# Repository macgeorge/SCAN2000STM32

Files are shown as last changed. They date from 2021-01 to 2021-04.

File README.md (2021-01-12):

# SCAN2000-20 ScanCard for DMM6500 using an STM32 microcontrller
Please see the [project page](https://christidis.info/index.php/personal-projects/keithley-dmm-scanner-card-with-ssr) for more details

The repository includes
1. The schematics of the Scanner Card
2. The Bill of Materials
3. The Gerber files to build a Scanner Card
4. The STM32G070 code as well as the executable

The scanner card has been tested with a Keithley DMM6500 multimeter. It is also compatible with the Keithley 2000series multimeter. Jumper links can be used to change the identity of the scanner card (current configuration: 2000-20).

The solid state relays used are 160V capable (recommended 160V, absolute maximum 200V). Please do not measure voltages higher than that. Creepage between the HV circuit and the LV (control circuit) is adequate for 300V. 

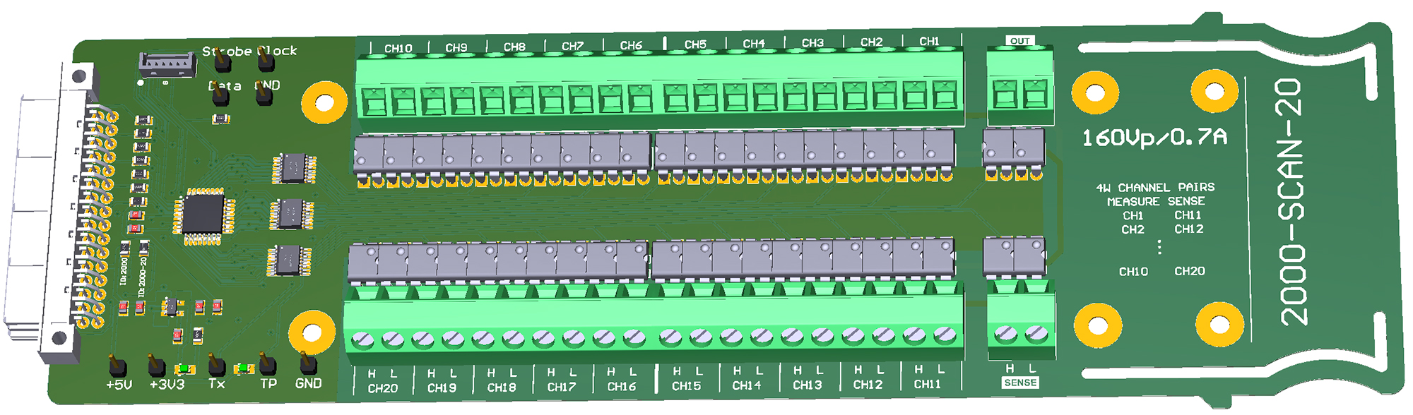
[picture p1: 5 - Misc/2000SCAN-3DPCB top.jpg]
ScanCardImage


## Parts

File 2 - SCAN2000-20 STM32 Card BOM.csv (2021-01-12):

Comment | Description | Designator | Footprint | LibRef | Quantity
TestPoint | Testpoint | +3V3, +5V, Clock, Data, GND, Strobe, TP, Tx | HDR1 | TestPoint | 9
Cap_1u_16V_0805 | Capacitor | C1, C2, C3, C4 | 0805 C | Cap_1u_16V_0805 | 4
Cap_100N_50V_0805 | Capacitor | C5, C6, C7 | 0805 C | Cap_100N_50V_0805 | 3
LED Green 0805 | Typical INFRARED GaAs LED | D1, D2 | 0805_G_LED | LED_Green_0805 | 2
SMT32G070 | STM32G070KBT6 LQFP32 | IC1 | LQFP-32_M | STM32G070KBT6 | 1
Molex 85050-0000 | Molex 85050-0000 | J1 | MOLEX 85050-0000 | Molex 85050-0000 | 1
6-pin 2.54mm header | Header, 6-Pin | P1 | Molex Picoblade 6way | Header 6 | 1
Conn_Phoenix_1869295 | Connector 10pin 5.08mm Phoenix 1869295 | P2, P3, P4, P5 | CONN X10 PHOENIX 1869295 | Conn_Phoenix_1869295 | 4
Conn_Phoenix_1869211 | Connector 2pin 5.08mm Phoenix 1869211 | P6, P7 | CONN X2 PHOENIX 1869211 | Conn_Phoenix_1869211 | 2
Res_330R_0805 | Resistor | R1, R2, R3, R4, R11 | 0805 R | Res_330R_0805 | 5
Res_0Ohm_0805 | Resistor | R5, R10 | 0805 R | Res_0Ohm_0805 | 2
Res_10K0_0805 | Resistor | R6, R7, R8, R9 | 0805 R | Res_10K0_0805 | 4
Res_330R_Pack8 | Isolated Resistor Network | R12, R13, R14, R15, R16, R17 | QSOP-QR16_M | Res_330R_Pack8 | 6
Res_2m_2512 | Resistor | R18, R19, R20, R21, R22, R23, R24, R25 | 2512 R | Res_2m0_2512 | 8
3.3V LDO | Single Output Fast Transient Response LDO, 200 mA, Fixed 3.3 V Output, 1.7 to 5.5 V Input, with Reverse Current Protection, 5-pin SOT-23 (DBV), -40 to 85 degC, Green (RoHS & no Sb/Br) | U1 | SOT-23-CT5_M | TPS73233DBVR | 1
TLP3558A | 4-Pin Phototransistor Optocoupler | U2, U3, U4, U5, U6, U7, U8, U9, U10, U11, U12, U13, U14, U15, U16, U17, U18, U19, U20, U21, U22, U23, U24, U25, U26, U27, U28, U29, U30, U31, U32, U33, U34, U35, U36, U37, U38, U39, U40, U41, U42, U43, U44, U45 | DIP4 - HV | TLP3558A | 44

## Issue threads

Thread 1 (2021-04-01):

Missing main.h file

cjkraz, 2021-04-01:
Can't compile due to missing "main.h" header in "SCAN2000.c".

fssup, 2021-05-03:
Haven't tried compiling yet, but it looks to my eye that everything is included in the c file, hence not needing a head (.h) file. Probably you need to fix your makefile? Can you post your makefile you're trying to get working?

cjkraz, 2021-11-26:
I'm using the Arduino IDE to compile this source right now. (I typically develop on TI Devices).

The updates are a major improvement. The issue I'm currently facing is around the USART4 definition:

```
C:\Users\Work\OneDrive\Documents\Arduino\sketch_nov26a\sketch_nov26a.ino: In function 'int fputc(int, FILE*)':
sketch_nov26a:199:34: error: 'USART4' was not declared in this scope; did you mean 'USART1'?
  199 |   while(LL_USART_IsActiveFlag_TC(USART4) != 1);
      |                                  ^~~~~~
      |                                  USART1
sketch_nov26a:200:27: error: 'USART4' was not declared in this scope; did you mean 'USART1'?
  200 |   LL_USART_TransmitData8 (USART4, charac);
      |                           ^~~~~~
      |                           USART1
C:\Users\Work\OneDrive\Documents\Arduino\sketch_nov26a\sketch_nov26a.ino: In function 'void USART4_Init()':
sketch_nov26a:251:28: error: 'LL_APB1_GRP1_PERIPH_USART4' was not declared in this scope; did you mean 'LL_APB1_GRP1_PERIPH_USART2'?
  251 |   LL_APB1_GRP1_EnableClock(LL_APB1_GRP1_PERIPH_USART4);
      |                            ^~~~~~~~~~~~~~~~~~~~~~~~~~
      |                            LL_APB1_GRP1_PERIPH_USART2
sketch_nov26a:273:17: error: 'USART4' was not declared in this scope; did you mean 'USART1'?
  273 |   LL_USART_Init(USART4, &USART_InitStruct);
      |                 ^~~~~~
      |                 USART1
sketch_nov26a:286:34: error: 'LL_DMAMUX_REQ_USART4_TX' was not declared in this scope; did you mean 'LL_DMAMUX_REQ_USART2_TX'?
  286 |   DMA_InitStruct.PeriphRequest = LL_DMAMUX_REQ_USART4_TX;
      |                                  ^~~~~~~~~~~~~~~~~~~~~~~
      |                                  LL_DMAMUX_REQ_USART2_TX
C:\Users\Work\OneDrive\Documents\Arduino\sketch_nov26a\sketch_nov26a.ino: In function 'void UARTSendDMA()':
sketch_nov26a:299:34: error: 'USART4' was not declared in this scope; did you mean 'USART1'?
  299 |   while(LL_USART_IsActiveFlag_TC(USART4) != 1); // wait for previous transfer to finish
      |                                  ^~~~~~
      |                                  USART1
In file included from C:\Users\Work\AppData\Local\Arduino15\packages\STMicroelectronics\hardware\stm32\2.1.0\cores\arduino/stm32/clock.h:19,
                 from C:\Users\Work\AppData\Local\Arduino15\packages\STMicroelectronics\hardware\stm32\2.1.0\cores\arduino/wiring_time.h:23,
                 from C:\Users\Work\AppData\Local\Arduino15\packages\STMicroelectronics\hardware\stm32\2.1.0\cores\arduino/wiring.h:38,
                 from C:\Users\Work\AppData\Local\Arduino15\packages\STMicroelectronics\hardware\stm32\2.1.0\cores\arduino/Arduino.h:36,
                 from sketch\sketch_nov26a.ino.cpp:1:
C:\Users\Work\OneDrive\Documents\Arduino\sketch_nov26a\sketch_nov26a.ino: At global scope:
C:\Users\Work\AppData\Local\Arduino15\packages\STMicroelectronics\hardware\stm32\2.1.0\cores\arduino/stm32/stm32_def.h:109:25: error: variable or field '_Error_Handler' declared void
  109 | #define Error_Handler() _Error_Handler(__FILE__, __LINE__)
      |                         ^~~~~~~~~~~~~~
C:\Users\Work\OneDrive\Documents\Arduino\sketch_nov26a\sketch_nov26a.ino:558:6: note: in expansion of macro 'Error_Handler'
  558 | void Error_Handler()
      |      ^~~~~~~~~~~~~
exit status 1
'USART4' was not declared in this scope; did you mean 'USART1'?

```

cjkraz, 2021-12-13:
This should be closed. I had the wrong board selected. Your updates did resolve a number of issues I originally had with the code base.

Really appreciate the update!

Closed 2021-12-13.

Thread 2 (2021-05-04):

Include full sources and schematics

ddavidebor, 2021-05-04:
Hi,

I would like to use this as a source project to create the thermocouple card.
Could you add to the repo:
- full altium proj (PcbDoc, SchDoc, PrjPcb, etc)
- Full STM32 project including makefile and IDE data

cjkraz, 2021-11-26:
I believe this may be made in KiCad. I am interested in the design files if willing to share. I was looking at implementing a pure analog solution with shift registers to work around the issues of programming an MCU to handle the bit stream from the DMM6500; adjusting this project would be an easy starting point.

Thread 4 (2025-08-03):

Gerber Drillfiles

ep092, 2025-08-03:
SCAN2000-20 PCB.TXT has an offset to gerber layers
Holesize in SCAN2000-20 PCB-5_PTH_Drill.gbr is partially different then in SCAN2000-20 PCB.TXT

Could you please share the Altium files?

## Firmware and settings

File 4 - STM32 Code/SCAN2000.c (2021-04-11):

#include <stdio.h>
#include <string.h>
#include "stm32g0xx_ll_rcc.h"
#include "stm32g0xx_ll_bus.h"
#include "stm32g0xx_ll_system.h"
#include "stm32g0xx_ll_exti.h"
#include "stm32g0xx_ll_cortex.h"
#include "stm32g0xx_ll_utils.h"
#include "stm32g0xx_ll_pwr.h"
#include "stm32g0xx_ll_dma.h"
#include "stm32g0xx_ll_usart.h"
#include "stm32g0xx_ll_gpio.h"

#define MAXALLOWEDONCHANNELS 6

#define CH21STATEOFF		0
#define CH21STATEOUT		1
#define CH21STATESENSE	2
#define CH21REQOFF			0
#define CH21REQOUT			1
#define CH21REQSENSE		2
#define CH21NOREQ				3

void SystemClock_Config(void);
void GPIO_Init(void);
void USART4_Init(void);
void UARTSendDMA(void);

uint64_t receivedSequence = 0;
uint8_t receivedCounter = 0;
int8_t numberOfChannelsActive = 0;
uint32_t channelState = 0;
uint8_t channel21State = CH21STATEOFF;
uint8_t channel21Req = CH21NOREQ;
uint8_t channel21DMMCommand = CH21REQOFF;
uint8_t channelSequence[] = {11, 12, 13, 14, 15, 16, 17, 18, 19, 20, 1, 2, 3, 4, 5, 6, 7 , 8, 9, 10, 21};
GPIO_TypeDef* GPIOsequence[] = {GPIOA, GPIOA, GPIOA, GPIOA, GPIOB, GPIOB, GPIOB, GPIOB, GPIOB, GPIOB, GPIOA, GPIOB, GPIOB, GPIOB, GPIOA, GPIOA, GPIOA, GPIOA, GPIOA, GPIOA};
uint32_t PinSequence[] = {LL_GPIO_PIN_10, LL_GPIO_PIN_11, LL_GPIO_PIN_12, LL_GPIO_PIN_15, LL_GPIO_PIN_3, LL_GPIO_PIN_4, LL_GPIO_PIN_5, LL_GPIO_PIN_6, LL_GPIO_PIN_7, LL_GPIO_PIN_8, LL_GPIO_PIN_8, LL_GPIO_PIN_2, LL_GPIO_PIN_1, LL_GPIO_PIN_0, LL_GPIO_PIN_7, LL_GPIO_PIN_6, LL_GPIO_PIN_5, LL_GPIO_PIN_4, LL_GPIO_PIN_3, LL_GPIO_PIN_2};
uint8_t uartsinglemessage[40], uartbuffer[2000], uarttransmitbuffer[2000];	
int main(void)
{
  LL_APB2_GRP1_EnableClock(LL_APB2_GRP1_PERIPH_SYSCFG);
  LL_APB1_GRP1_EnableClock(LL_APB1_GRP1_PERIPH_PWR);

  SystemClock_Config();

  GPIO_Init();
	LL_GPIO_ResetOutputPin(GPIOA, LL_GPIO_PIN_1); /* turn on led */
  USART4_Init();
	printf("\n===============\nBoot\n");
	LL_GPIO_SetOutputPin(GPIOA, LL_GPIO_PIN_1); /* turn off led */
  
	while (1)
  {

	}
}

void EXTI4_15_IRQHandler(void)
{
  if (LL_EXTI_IsActiveRisingFlag_0_31(LL_EXTI_LINE_14) != RESET)
  {	/* Clock interrupt */
    LL_EXTI_ClearRisingFlag_0_31(LL_EXTI_LINE_14);
		receivedSequence = receivedSequence << 1;
		receivedSequence |= LL_GPIO_IsInputPinSet(GPIOB, LL_GPIO_PIN_9);
		receivedCounter++;
  }
  if (LL_EXTI_IsActiveRisingFlag_0_31(LL_EXTI_LINE_15) != RESET)
  {
		/* Strobe Interrupt */
    LL_EXTI_ClearRisingFlag_0_31(LL_EXTI_LINE_15);
		LL_GPIO_TogglePin(GPIOA, LL_GPIO_PIN_1); /* toggle led */
		uartbuffer[0] = '\0';
		
		if (receivedCounter != 48)	{
			sprintf((char *)uartsinglemessage, "Warning: 48 clocks not received, %d\n", receivedCounter);
			strcat((char *)uartbuffer, (char *)uartsinglemessage);
		}
		
		if (receivedSequence != 0x0) {
			/* if no command, do nothing */
			uint8_t counter;
			for (counter = 0 ; counter<20 ; counter++) {
				if ((receivedSequence & ((uint64_t)1<<(2*counter))) !=0) {
					/* turn off channel */
					LL_GPIO_ResetOutputPin(GPIOsequence[channelSequence[counter]-1], PinSequence[channelSequence[counter]-1]);
					numberOfChannelsActive--;
					channelState &= ~((long)1<<(channelSequence[counter]-1));
					sprintf((char *)uartsinglemessage, "CH%d OFF\n", channelSequence[counter]);
					strcat((char *)uartbuffer, (char *)uartsinglemessage);
					if (numberOfChannelsActive<0) 
					{
						sprintf((char *)uartsinglemessage, "Warning too many ssr off requests\n");
						strcat((char *)uartbuffer, (char *)uartsinglemessage);
						numberOfChannelsActive = 0;
					}
				}
				
				if ((receivedSequence & ((uint64_t)1<<(2*counter+1))) !=0) {
					/* turn on channel */
					if (numberOfChannelsActive < MAXALLOWEDONCHANNELS) {
						LL_GPIO_SetOutputPin(GPIOsequence[channelSequence[counter]-1], PinSequence[channelSequence[counter]-1]);
						numberOfChannelsActive++;
						channelState |= (1<<(channelSequence[counter]-1));
						sprintf((char *)uartsinglemessage, "CH%d ON\n", channelSequence[counter]);
						strcat((char *)uartbuffer, (char *)uartsinglemessage);
					}
					else
					{
						sprintf((char *)uartsinglemessage, "Error, maximum allowed of on ssrs reached. CH%d did not switch on\n", channelSequence[counter]);
						strcat((char *)uartbuffer, (char *)uartsinglemessage);;
					}
				}
			}
			
			/* channel 21 */
			if ((channelState & 0xFFC00)==0) {
				/* If channels 11 to 20 not used, turn off both bus2 switches */
					channel21Req = CH21REQOFF;
			}
			else {
				/* But turn the bus on again, on the next command for CH11 to CH20 use */
				channel21Req = channel21DMMCommand;
			}
			if ((receivedSequence & ((uint64_t)1<<(2*20))) !=0) {
					/* switch bus2 to out */
				channel21Req = CH21REQOUT;
				channel21DMMCommand = CH21REQOUT;
			}
			if ((receivedSequence & ((uint64_t)1<<(2*20+1))) !=0) {
					/* switch bus2 to sense */
				channel21Req = CH21REQSENSE;
				channel21DMMCommand = CH21REQSENSE;
			}
			
			if ((channel21Req == CH21REQOFF) && channel21State != CH21STATEOFF) {
				LL_GPIO_ResetOutputPin(GPIOA, LL_GPIO_PIN_9);
				LL_GPIO_ResetOutputPin(GPIOC, LL_GPIO_PIN_6);
				channel21State = CH21STATEOFF;
				numberOfChannelsActive--;
				sprintf((char *)uartsinglemessage, "CH21 OFF\n");
				strcat((char *)uartbuffer, (char *)uartsinglemessage);
			}
			
			if ((channel21Req == CH21REQOUT) && (channel21State != CH21STATEOUT)) {
				if ((numberOfChannelsActive <= MAXALLOWEDONCHANNELS - 1) || ((numberOfChannelsActive <= MAXALLOWEDONCHANNELS) && (channel21State != CH21STATEOFF))) {
					LL_GPIO_ResetOutputPin(GPIOA, LL_GPIO_PIN_9);
					LL_GPIO_SetOutputPin(GPIOC, LL_GPIO_PIN_6);
					if (channel21State == CH21STATEOFF) numberOfChannelsActive++;
					channel21State = CH21STATEOUT;
					sprintf((char *)uartsinglemessage, "CH21 OUT\n");
					strcat((char *)uartbuffer, (char *)uartsinglemessage);
				}
				else
				{
					sprintf((char *) uartsinglemessage, "Error, maximum allowed of on ssrs reached. Bus2 Mux did not switch on\n");
					strcat((char *)uartbuffer, (char *)uartsinglemessage);
				}
			}
			
			if ((channel21Req == CH21REQSENSE) && channel21State != CH21STATESENSE ) {
				if ((numberOfChannelsActive <= MAXALLOWEDONCHANNELS - 1) || ((numberOfChannelsActive <= MAXALLOWEDONCHANNELS) && (channel21State != CH21STATEOFF))) {
					LL_GPIO_ResetOutputPin(GPIOC, LL_GPIO_PIN_6);
					LL_GPIO_SetOutputPin(GPIOA, LL_GPIO_PIN_9);
					if (channel21State == CH21STATEOFF) numberOfChannelsActive++;
					channel21State = CH21STATESENSE;
					sprintf((char *)uartsinglemessage, "CH21 SENSE\n");
					strcat((char *)uartbuffer, (char *)uartsinglemessage);
				}
				else
				{
					sprintf((char *)uartsinglemessage, "Error, maximum allowed of on ssrs reached. Bus2 Mux did not switch on\n");
					strcat((char *)uartbuffer, (char *)uartsinglemessage);
				}
			}
		}
		channel21Req = CH21NOREQ;
		receivedSequence = 0x0;
		receivedCounter = 0;
		if (uartbuffer[0] != '\0') UARTSendDMA();
  }
	
}

void DMA1_Channel1_IRQHandler(void)
{
	if (LL_DMA_IsActiveFlag_TC1(DMA1))
	{
		LL_DMA_ClearFlag_TC1(DMA1);
		LL_DMA_DisableChannel(DMA1, LL_DMA_CHANNEL_1);
	}
	
}

int fputc(int ch, FILE* fil) {
	uint8_t charac = ch;
	/* Send over debug USART */

	while(LL_USART_IsActiveFlag_TC(USART4) != 1);
	LL_USART_TransmitData8 (USART4, charac);
	return ch;
}

void SystemClock_Config(void)
{
  LL_FLASH_SetLatency(LL_FLASH_LATENCY_2);
  if(LL_FLASH_GetLatency() != LL_FLASH_LATENCY_2)
  {
    Error_Handler();  
  };

  /* HSI configuration and activation */
  LL_RCC_HSI_Enable();
  while(LL_RCC_HSI_IsReady() != 1)
  {
  };

  /* Main PLL configuration and activation */
  LL_RCC_PLL_ConfigDomain_SYS(LL_RCC_PLLSOURCE_HSI, LL_RCC_PLLM_DIV_1, 8, LL_RCC_PLLR_DIV_2);
  LL_RCC_PLL_Enable();
  LL_RCC_PLL_EnableDomain_SYS();
  while(LL_RCC_PLL_IsReady() != 1)
  {
  };

  /* Set AHB prescaler*/
  LL_RCC_SetAHBPrescaler(LL_RCC_SYSCLK_DIV_1);

  /* Sysclk activation on the main PLL */
  LL_RCC_SetSysClkSource(LL_RCC_SYS_CLKSOURCE_PLL);
  while(LL_RCC_GetSysClkSource() != LL_RCC_SYS_CLKSOURCE_STATUS_PLL)
  {
  };

  /* Set APB1 prescaler*/
  LL_RCC_SetAPB1Prescaler(LL_RCC_APB1_DIV_1);
  LL_Init1msTick(64000000);
  LL_SYSTICK_SetClkSource(LL_SYSTICK_CLKSOURCE_HCLK);
  LL_SetSystemCoreClock(64000000);
  /* Update CMSIS variable (which can be updated also through SystemCoreClockUpdate function) */
  LL_SetSystemCoreClock(64000000);
}


void USART4_Init(void)
{
  LL_USART_InitTypeDef USART_InitStruct;
  LL_GPIO_InitTypeDef GPIO_InitStruct;
	LL_DMA_InitTypeDef DMA_InitStruct;

  LL_APB1_GRP1_EnableClock(LL_APB1_GRP1_PERIPH_USART4);
  LL_IOP_GRP1_EnableClock(LL_IOP_GRP1_PERIPH_GPIOA);
	LL_AHB1_GRP1_EnableClock(LL_AHB1_GRP1_PERIPH_DMA1);
  
  /**USART4 GPIO Configuration  
  PA0   ------> USART4_TX 
  */
  GPIO_InitStruct.Pin = LL_GPIO_PIN_0;
  GPIO_InitStruct.Mode = LL_GPIO_MODE_ALTERNATE;
  GPIO_InitStruct.Speed = LL_GPIO_SPEED_FREQ_LOW;
  GPIO_InitStruct.OutputType = LL_GPIO_OUTPUT_OPENDRAIN;
  GPIO_InitStruct.Pull = LL_GPIO_PULL_UP;
  GPIO_InitStruct.Alternate = LL_GPIO_AF_4;
  LL_GPIO_Init(GPIOA, &GPIO_InitStruct);

  USART_InitStruct.PrescalerValue = LL_USART_PRESCALER_DIV1;
  USART_InitStruct.BaudRate = 115200;
  USART_InitStruct.DataWidth = LL_USART_DATAWIDTH_8B;
  USART_InitStruct.StopBits = LL_USART_STOPBITS_1;
  USART_InitStruct.Parity = LL_USART_PARITY_NONE;
  USART_InitStruct.TransferDirection = LL_USART_DIRECTION_TX;
  USART_InitStruct.OverSampling = LL_USART_OVERSAMPLING_16;
  LL_USART_Init(USART4, &USART_InitStruct);
  LL_USART_ConfigHalfDuplexMode(USART4);

	/* DMA Setup */
	DMA_InitStruct.Direction = LL_DMA_DIRECTION_MEMORY_TO_PERIPH;
	DMA_InitStruct.Mode = LL_DMA_MODE_NORMAL;
	DMA_InitStruct.NbData = 0;
	DMA_InitStruct.MemoryOrM2MDstAddress = (uint32_t)uarttransmitbuffer;
	DMA_InitStruct.MemoryOrM2MDstDataSize = LL_DMA_MDATAALIGN_BYTE;
	DMA_InitStruct.MemoryOrM2MDstIncMode = LL_DMA_MEMORY_INCREMENT;
	DMA_InitStruct.PeriphOrM2MSrcAddress = LL_USART_DMA_GetRegAddr(USART4, LL_USART_DMA_REG_DATA_TRANSMIT);
	DMA_InitStruct.PeriphOrM2MSrcDataSize = LL_DMA_MDATAALIGN_BYTE;
	DMA_InitStruct.PeriphOrM2MSrcIncMode = LL_DMA_MEMORY_NOINCREMENT;
	DMA_InitStruct.PeriphRequest = LL_DMAMUX_REQ_USART4_TX;
	DMA_InitStruct.Priority = LL_DMA_PRIORITY_MEDIUM;
	LL_DMA_Init(DMA1, LL_DMA_CHANNEL_1, &DMA_InitStruct);
	
	LL_DMA_EnableIT_TC(DMA1, LL_DMA_CHANNEL_1);
	NVIC_SetPriority(DMA1_Channel1_IRQn, 4);
  NVIC_EnableIRQ(DMA1_Channel1_IRQn);
	
  LL_USART_Enable(USART4);
}

void UARTSendDMA(void) {
	uint8_t uartstringlength;
	while(LL_USART_IsActiveFlag_TC(USART4) != 1); // wait for previous transfer to finish
	strcpy((char *)uarttransmitbuffer, (char *)uartbuffer);
	uartstringlength = strlen((char *)uarttransmitbuffer);
	LL_DMA_SetDataLength(DMA1, LL_DMA_CHANNEL_1, uartstringlength);
	LL_DMA_EnableChannel(DMA1, LL_DMA_CHANNEL_1);
}

void GPIO_Init(void)
{
  LL_EXTI_InitTypeDef EXTI_InitStruct;
  LL_GPIO_InitTypeDef GPIO_InitStruct;

  /* GPIO Ports Clock Enable */
  LL_IOP_GRP1_EnableClock(LL_IOP_GRP1_PERIPH_GPIOB);
  LL_IOP_GRP1_EnableClock(LL_IOP_GRP1_PERIPH_GPIOC);
  LL_IOP_GRP1_EnableClock(LL_IOP_GRP1_PERIPH_GPIOA);

  LL_GPIO_ResetOutputPin(GPIOA, LL_GPIO_PIN_1);
  LL_GPIO_ResetOutputPin(GPIOA, LL_GPIO_PIN_2);
  LL_GPIO_ResetOutputPin(GPIOA, LL_GPIO_PIN_3);
  LL_GPIO_ResetOutputPin(GPIOA, LL_GPIO_PIN_4);
  LL_GPIO_ResetOutputPin(GPIOA, LL_GPIO_PIN_5);
  LL_GPIO_ResetOutputPin(GPIOA, LL_GPIO_PIN_6);
  LL_GPIO_ResetOutputPin(GPIOA, LL_GPIO_PIN_7);
  LL_GPIO_ResetOutputPin(GPIOB, LL_GPIO_PIN_0);
  LL_GPIO_ResetOutputPin(GPIOB, LL_GPIO_PIN_1);
  LL_GPIO_ResetOutputPin(GPIOB, LL_GPIO_PIN_2);
  LL_GPIO_ResetOutputPin(GPIOA, LL_GPIO_PIN_8);
  LL_GPIO_ResetOutputPin(GPIOA, LL_GPIO_PIN_9);
  LL_GPIO_ResetOutputPin(GPIOC, LL_GPIO_PIN_6);
  LL_GPIO_ResetOutputPin(GPIOA, LL_GPIO_PIN_10);
  LL_GPIO_ResetOutputPin(GPIOA, LL_GPIO_PIN_11);
  LL_GPIO_ResetOutputPin(GPIOA, LL_GPIO_PIN_12);
  LL_GPIO_ResetOutputPin(GPIOA, LL_GPIO_PIN_15);
  LL_GPIO_ResetOutputPin(GPIOB, LL_GPIO_PIN_3);
  LL_GPIO_ResetOutputPin(GPIOB, LL_GPIO_PIN_4);
  LL_GPIO_ResetOutputPin(GPIOB, LL_GPIO_PIN_5);
  LL_GPIO_ResetOutputPin(GPIOB, LL_GPIO_PIN_6);
  LL_GPIO_ResetOutputPin(GPIOB, LL_GPIO_PIN_7);
  LL_GPIO_ResetOutputPin(GPIOB, LL_GPIO_PIN_8);

	/* PB9 (Data) */
	GPIO_InitStruct.Pin = LL_GPIO_PIN_9;
  GPIO_InitStruct.Mode = LL_GPIO_MODE_INPUT;
  GPIO_InitStruct.Pull = LL_GPIO_PULL_NO;
  GPIO_InitStruct.Speed = LL_GPIO_SPEED_FREQ_VERY_HIGH;
	LL_GPIO_Init(GPIOB, &GPIO_InitStruct);

	/* PA1 (LED) */
	GPIO_InitStruct.Pin = LL_GPIO_PIN_1;
  GPIO_InitStruct.Mode = LL_GPIO_MODE_OUTPUT;
  GPIO_InitStruct.Speed = LL_GPIO_SPEED_FREQ_LOW;
  GPIO_InitStruct.OutputType = LL_GPIO_OUTPUT_PUSHPULL;
  GPIO_InitStruct.Pull = LL_GPIO_PULL_NO;
	GPIO_InitStruct.Speed = LL_GPIO_SPEED_FREQ_VERY_HIGH;
  LL_GPIO_Init(GPIOA, &GPIO_InitStruct);

  /* PA2 (CH20) */
  GPIO_InitStruct.Pin = LL_GPIO_PIN_2;
  GPIO_InitStruct.Mode = LL_GPIO_MODE_OUTPUT;
  GPIO_InitStruct.Speed = LL_GPIO_SPEED_FREQ_LOW;
  GPIO_InitStruct.OutputType = LL_GPIO_OUTPUT_PUSHPULL;
  GPIO_InitStruct.Pull = LL_GPIO_PULL_NO;
  LL_GPIO_Init(GPIOA, &GPIO_InitStruct);

  /* PA3 (CH19) */
  GPIO_InitStruct.Pin = LL_GPIO_PIN_3;
  GPIO_InitStruct.Mode = LL_GPIO_MODE_OUTPUT;
  GPIO_InitStruct.Speed = LL_GPIO_SPEED_FREQ_LOW;
  GPIO_InitStruct.OutputType = LL_GPIO_OUTPUT_PUSHPULL;
  GPIO_InitStruct.Pull = LL_GPIO_PULL_NO;
  LL_GPIO_Init(GPIOA, &GPIO_InitStruct);

  /* PA4 (CH18) */
  GPIO_InitStruct.Pin = LL_GPIO_PIN_4;
  GPIO_InitStruct.Mode = LL_GPIO_MODE_OUTPUT;
  GPIO_InitStruct.Speed = LL_GPIO_SPEED_FREQ_LOW;
  GPIO_InitStruct.OutputType = LL_GPIO_OUTPUT_PUSHPULL;
  GPIO_InitStruct.Pull = LL_GPIO_PULL_NO;
  LL_GPIO_Init(GPIOA, &GPIO_InitStruct);

  /* PA5 (CH17) */
  GPIO_InitStruct.Pin = LL_GPIO_PIN_5;
  GPIO_InitStruct.Mode = LL_GPIO_MODE_OUTPUT;
  GPIO_InitStruct.Speed = LL_GPIO_SPEED_FREQ_LOW;
  GPIO_InitStruct.OutputType = LL_GPIO_OUTPUT_PUSHPULL;
  GPIO_InitStruct.Pull = LL_GPIO_PULL_NO;
  LL_GPIO_Init(GPIOA, &GPIO_InitStruct);

  /* PA6 (CH16) */
  GPIO_InitStruct.Pin = LL_GPIO_PIN_6;
  GPIO_InitStruct.Mode = LL_GPIO_MODE_OUTPUT;
  GPIO_InitStruct.Speed = LL_GPIO_SPEED_FREQ_LOW;
  GPIO_InitStruct.OutputType = LL_GPIO_OUTPUT_PUSHPULL;
  GPIO_InitStruct.Pull = LL_GPIO_PULL_NO;
  LL_GPIO_Init(GPIOA, &GPIO_InitStruct);

  /* PA7 (CH15) */
  GPIO_InitStruct.Pin = LL_GPIO_PIN_7;
  GPIO_InitStruct.Mode = LL_GPIO_MODE_OUTPUT;
  GPIO_InitStruct.Speed = LL_GPIO_SPEED_FREQ_LOW;
  GPIO_InitStruct.OutputType = LL_GPIO_OUTPUT_PUSHPULL;
  GPIO_InitStruct.Pull = LL_GPIO_PULL_NO;
  LL_GPIO_Init(GPIOA, &GPIO_InitStruct);

   /* PB0 (CH14) */
  GPIO_InitStruct.Pin = LL_GPIO_PIN_0;
  GPIO_InitStruct.Mode = LL_GPIO_MODE_OUTPUT;
  GPIO_InitStruct.Speed = LL_GPIO_SPEED_FREQ_LOW;
  GPIO_InitStruct.OutputType = LL_GPIO_OUTPUT_PUSHPULL;
  GPIO_InitStruct.Pull = LL_GPIO_PULL_NO;
  LL_GPIO_Init(GPIOB, &GPIO_InitStruct);

  /* PB1 (CH13) */
  GPIO_InitStruct.Pin = LL_GPIO_PIN_1;
  GPIO_InitStruct.Mode = LL_GPIO_MODE_OUTPUT;
  GPIO_InitStruct.Speed = LL_GPIO_SPEED_FREQ_LOW;
  GPIO_InitStruct.OutputType = LL_GPIO_OUTPUT_PUSHPULL;
  GPIO_InitStruct.Pull = LL_GPIO_PULL_NO;
  LL_GPIO_Init(GPIOB, &GPIO_InitStruct);

  /* PB2 (CH12) */
  GPIO_InitStruct.Pin = LL_GPIO_PIN_2;
  GPIO_InitStruct.Mode = LL_GPIO_MODE_OUTPUT;
  GPIO_InitStruct.Speed = LL_GPIO_SPEED_FREQ_LOW;
  GPIO_InitStruct.OutputType = LL_GPIO_OUTPUT_PUSHPULL;
  GPIO_InitStruct.Pull = LL_GPIO_PULL_NO;
  LL_GPIO_Init(GPIOB, &GPIO_InitStruct);

  /* PA8 (CH11) */
  GPIO_InitStruct.Pin = LL_GPIO_PIN_8;
  GPIO_InitStruct.Mode = LL_GPIO_MODE_OUTPUT;
  GPIO_InitStruct.Speed = LL_GPIO_SPEED_FREQ_LOW;
  GPIO_InitStruct.OutputType = LL_GPIO_OUTPUT_PUSHPULL;
  GPIO_InitStruct.Pull = LL_GPIO_PULL_NO;
  LL_GPIO_Init(GPIOA, &GPIO_InitStruct);

  /* PA9 (Bus Sense) */
  GPIO_InitStruct.Pin = LL_GPIO_PIN_9;
  GPIO_InitStruct.Mode = LL_GPIO_MODE_OUTPUT;
  GPIO_InitStruct.Speed = LL_GPIO_SPEED_FREQ_LOW;
  GPIO_InitStruct.OutputType = LL_GPIO_OUTPUT_PUSHPULL;
  GPIO_InitStruct.Pull = LL_GPIO_PULL_NO;
  LL_GPIO_Init(GPIOA, &GPIO_InitStruct);

  /* PC6 (Bus In) */
  GPIO_InitStruct.Pin = LL_GPIO_PIN_6;
  GPIO_InitStruct.Mode = LL_GPIO_MODE_OUTPUT;
  GPIO_InitStruct.Speed = LL_GPIO_SPEED_FREQ_LOW;
  GPIO_InitStruct.OutputType = LL_GPIO_OUTPUT_PUSHPULL;
  GPIO_InitStruct.Pull = LL_GPIO_PULL_NO;
  LL_GPIO_Init(GPIOC, &GPIO_InitStruct);

  /* PA10 (CH1) */
  GPIO_InitStruct.Pin = LL_GPIO_PIN_10;
  GPIO_InitStruct.Mode = LL_GPIO_MODE_OUTPUT;
  GPIO_InitStruct.Speed = LL_GPIO_SPEED_FREQ_LOW;
  GPIO_InitStruct.OutputType = LL_GPIO_OUTPUT_PUSHPULL;
  GPIO_InitStruct.Pull = LL_GPIO_PULL_NO;
  LL_GPIO_Init(GPIOA, &GPIO_InitStruct);

  /* PA11 (CH2) */
  GPIO_InitStruct.Pin = LL_GPIO_PIN_11;
  GPIO_InitStruct.Mode = LL_GPIO_MODE_OUTPUT;
  GPIO_InitStruct.Speed = LL_GPIO_SPEED_FREQ_LOW;
  GPIO_InitStruct.OutputType = LL_GPIO_OUTPUT_PUSHPULL;
  GPIO_InitStruct.Pull = LL_GPIO_PULL_NO;
  LL_GPIO_Init(GPIOA, &GPIO_InitStruct);

  /* PA12 (CH3) */
  GPIO_InitStruct.Pin = LL_GPIO_PIN_12;
  GPIO_InitStruct.Mode = LL_GPIO_MODE_OUTPUT;
  GPIO_InitStruct.Speed = LL_GPIO_SPEED_FREQ_LOW;
  GPIO_InitStruct.OutputType = LL_GPIO_OUTPUT_PUSHPULL;
  GPIO_InitStruct.Pull = LL_GPIO_PULL_NO;
  LL_GPIO_Init(GPIOA, &GPIO_InitStruct);

  /* PA15 (CH4) */
  GPIO_InitStruct.Pin = LL_GPIO_PIN_15;
  GPIO_InitStruct.Mode = LL_GPIO_MODE_OUTPUT;
  GPIO_InitStruct.Speed = LL_GPIO_SPEED_FREQ_LOW;
  GPIO_InitStruct.OutputType = LL_GPIO_OUTPUT_PUSHPULL;
  GPIO_InitStruct.Pull = LL_GPIO_PULL_NO;
  LL_GPIO_Init(GPIOA, &GPIO_InitStruct);

  /* PB3 (CH5) */
  GPIO_InitStruct.Pin = LL_GPIO_PIN_3;
  GPIO_InitStruct.Mode = LL_GPIO_MODE_OUTPUT;
  GPIO_InitStruct.Speed = LL_GPIO_SPEED_FREQ_LOW;
  GPIO_InitStruct.OutputType = LL_GPIO_OUTPUT_PUSHPULL;
  GPIO_InitStruct.Pull = LL_GPIO_PULL_NO;
  LL_GPIO_Init(GPIOB, &GPIO_InitStruct);

  /* PB4 (CH6) */
  GPIO_InitStruct.Pin = LL_GPIO_PIN_4;
  GPIO_InitStruct.Mode = LL_GPIO_MODE_OUTPUT;
  GPIO_InitStruct.Speed = LL_GPIO_SPEED_FREQ_LOW;
  GPIO_InitStruct.OutputType = LL_GPIO_OUTPUT_PUSHPULL;
  GPIO_InitStruct.Pull = LL_GPIO_PULL_NO;
  LL_GPIO_Init(GPIOB, &GPIO_InitStruct);

  /* PB5 (CH7) */
  GPIO_InitStruct.Pin = LL_GPIO_PIN_5;
  GPIO_InitStruct.Mode = LL_GPIO_MODE_OUTPUT;
  GPIO_InitStruct.Speed = LL_GPIO_SPEED_FREQ_LOW;
  GPIO_InitStruct.OutputType = LL_GPIO_OUTPUT_PUSHPULL;
  GPIO_InitStruct.Pull = LL_GPIO_PULL_NO;
  LL_GPIO_Init(GPIOB, &GPIO_InitStruct);

  /* PB6 (CH8) */
  GPIO_InitStruct.Pin = LL_GPIO_PIN_6;
  GPIO_InitStruct.Mode = LL_GPIO_MODE_OUTPUT;
  GPIO_InitStruct.Speed = LL_GPIO_SPEED_FREQ_LOW;
  GPIO_InitStruct.OutputType = LL_GPIO_OUTPUT_PUSHPULL;
  GPIO_InitStruct.Pull = LL_GPIO_PULL_NO;
  LL_GPIO_Init(GPIOB, &GPIO_InitStruct);

  /* PB7 (CH9) */
  GPIO_InitStruct.Pin = LL_GPIO_PIN_7;
  GPIO_InitStruct.Mode = LL_GPIO_MODE_OUTPUT;
  GPIO_InitStruct.Speed = LL_GPIO_SPEED_FREQ_LOW;
  GPIO_InitStruct.OutputType = LL_GPIO_OUTPUT_PUSHPULL;
  GPIO_InitStruct.Pull = LL_GPIO_PULL_NO;
  LL_GPIO_Init(GPIOB, &GPIO_InitStruct);

  /* PB8 (CH10) */
  GPIO_InitStruct.Pin = LL_GPIO_PIN_8;
  GPIO_InitStruct.Mode = LL_GPIO_MODE_OUTPUT;
  GPIO_InitStruct.Speed = LL_GPIO_SPEED_FREQ_LOW;
  GPIO_InitStruct.OutputType = LL_GPIO_OUTPUT_PUSHPULL;
  GPIO_InitStruct.Pull = LL_GPIO_PULL_NO;
  LL_GPIO_Init(GPIOB, &GPIO_InitStruct);
  
  /* PC14 (Clock) */
  LL_EXTI_SetEXTISource(LL_EXTI_CONFIG_PORTC, LL_EXTI_CONFIG_LINE14);
	EXTI_InitStruct.Line_0_31 = LL_EXTI_LINE_14;
  EXTI_InitStruct.LineCommand = ENABLE;
  EXTI_InitStruct.Mode = LL_EXTI_MODE_IT;
  EXTI_InitStruct.Trigger = LL_EXTI_TRIGGER_RISING;
  GPIO_InitStruct.Speed = LL_GPIO_SPEED_FREQ_VERY_HIGH;
	LL_EXTI_Init(&EXTI_InitStruct);
	LL_GPIO_SetPinPull(GPIOC, LL_GPIO_PIN_14, LL_GPIO_PULL_NO);
	LL_GPIO_SetPinMode(GPIOC, LL_GPIO_PIN_14, LL_GPIO_MODE_INPUT);

  /* PC15 (Strobe) */
	LL_EXTI_SetEXTISource(LL_EXTI_CONFIG_PORTC, LL_EXTI_CONFIG_LINE15);
	EXTI_InitStruct.Line_0_31 = LL_EXTI_LINE_15;
  EXTI_InitStruct.LineCommand = ENABLE;
  EXTI_InitStruct.Mode = LL_EXTI_MODE_IT;
  EXTI_InitStruct.Trigger = LL_EXTI_TRIGGER_RISING;
  GPIO_InitStruct.Speed = LL_GPIO_SPEED_FREQ_VERY_HIGH;
	LL_EXTI_Init(&EXTI_InitStruct);
	LL_GPIO_SetPinPull(GPIOC, LL_GPIO_PIN_15, LL_GPIO_PULL_NO);
	LL_GPIO_SetPinMode(GPIOC, LL_GPIO_PIN_15, LL_GPIO_MODE_INPUT);

  NVIC_SetPriority(EXTI4_15_IRQn, 1);
  NVIC_EnableIRQ(EXTI4_15_IRQn);
}

void Error_Handler(void)
{

}
